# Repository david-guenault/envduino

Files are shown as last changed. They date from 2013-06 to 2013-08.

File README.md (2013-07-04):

# Envduino Project

## Goals

  There was two main goals when i started this project. Having fun with electronics and create a cheap (really) environmental sensor.
  So there it is. Cheap, full featured and usable with either serial or ethernet connection. 
  
  Curently envduino only provide temperature, humidity, pressure and elevation. It should provide in the future light sensing and gaz sensing.

## Included

  envduino is made of a sketch file for arduino (only tested on mega and should not work en leonardo), a shell for getting values and settings preferences (saving not ready at the moment), a nagios/shinken/icinga plugin for checking environmental status and a little webapp for getting metrics and graph them.

## Envduino prototype wiring

### DHT22 

  DHT22 come with 4 pins from left to right when facing the grid
  
  ```

    DHT22                       ARDUINO MEGA 2560

    1 - VCC (3 to 5V)   -->     PIN 3.3V 
    2 - Data Out        -->     PIN 2 (this can be changed in the arduino sketch)
    3 - Not connected
    4 - Ground          -->     GROUND PIN

  ```

  Also connect a 10k resistor between DHT22's VCC AND DATA pins

### BMP085

  There are 7 pins from left to right (1 to 7). This is an i2c module. 

```
    BMP085                      ARDUINO MEGA 2560

    1 - 5V             
    2 - 3.3V            -->     3.3V
    3 - GROUND          -->     Ground
    4 - SDA             -->     PIN 43 SDA
    5 - SCL             -->     PIN 42 SCL
    6 - XCLR
    7 - EOC
```

### Schematic 

#### breadboard



#### logical 



## Envduino Shell

This shell allow to test envduino module and configure envduino module settings

```
------------------------------------------------

Welcome to Envduino Shell

(c) David GUENAULT

david.guenault@gmail.com

Released under GNU Affero General Public License

http://www.gnu.org/licenses

------------------------------------------------

> connect
Using default port and baudrate (/dev/ttyACM1,9600)
Connection to serial port OK

> temperature
temperature:24
> humidity
humidity:55
> 
```

## Envduino serial commands protocol

### Checking envduino is alive

```
   Syntax : ping
   Return : pong
```

### Thresholds

#### Setting 

 Settings thresholds is done through the envduino shell tool or through arduino serial console.

```
    syntax : t;[s];[t];[v]
    t define that the current command is a threshold setting command
    [s] is the sensor :
        h for humidity
        t for temperature
        p for pressure
    [t] is the threshold type. For the thow levels of alert (warning and critical)
        w for warning
        c for critical
    [v] is the threshold value. It's an integer within bounds of your sensor.
````

#### Reading 

```
    syntax : r
    Return : Temperature : w=-9999, c=-9999 | Humidity : w=-9999,c=-9999 | Pressure : w=-9999,c=-9999
```

#### Saving 

```
    Syntax : w (NOT IMPLEMENTED)
    Return : 
```

#### Visual status indicator

 Visual status is a way to define if mesured sensor values are within bounds or not by colored leds. 

 There are 3 leds on the project (red,yellow,gree). Each led is a visual status indicator. 
 * Green: OK
 * Yellow: WARNING
 * Red: CRITICAL

##### Controling leds

```
    Syntax : l;[led];[state]
    Return : 

    led should be one of the following :
    r for red
    y for yellow
    g for green

    state should be one of the following :
    0 for off
    1 for on
```

### geting sensors values

```
    Syntax : m;[sensor]
    Return : temperature:25

    sensor should be one of the following :
    h for humidity
    t for temperature
    p for pressure
```

## Preparing the environment

### DEBIAN/UBUNTU

envduino use the following libraries (allready included in this github space).

 * Adafruit DHT22 library : https://github.com/adafruit/DHT-sensor-library
 * Adafruit BMP085 library : https://github.com/adafruit/Adafruit-BMP085-Library
 
## Parts

### List

 * 1		10k Ω Resistance				
 * 3		330 Ω Resistance	
 * 1		DHT22 Humidity and Temperature Sensor	
 * 1		Arduino Mega	
 * 1		BMP085 Breakout (pressure and elevation)	
 * 1		Yellow LED 
 * 1		Red LED 
 * 1		Green LED 

### Where to buy 

I bought everything on amazon (no pub but it was cheaper). 
  
  * BMP085 pressure, elevation and temperature sensor (http://www.amazon.fr/gp/product/B0090XB5GQ/ref=oh_details_o02_s00_i00?ie=UTF8&psc=1)
  * DHT22 humidity and tempertature sensor (http://www.amazon.fr/gp/product/B005A9KJ4I/ref=oh_details_o04_s00_i00?ie=UTF8&psc=1)
  * Ethernet Shield (http://www.amazon.fr/gp/product/B00D6BGCO8/ref=oh_details_o03_s00_i00?ie=UTF8&psc=1)
  * Arduino mega clone (http://www.amazon.fr/Arduino-MEGA-2560-Board-Conseil/dp/B00C04P9VO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)
  * 10k resistor

You can also find the parts at the following websites
  
  * http://www.adafruit.com (US)
  * http://www.arduino.cc (for arduino mega and ethernet shield) (EU)
  * http://https://www.sparkfun.com (US)

As an alternative you can use the sainsmart bmp085 (cheaper) from : http://www.sainsmart.com/sainsmart-bmp085-digital-pressure-sensor-module-board.html

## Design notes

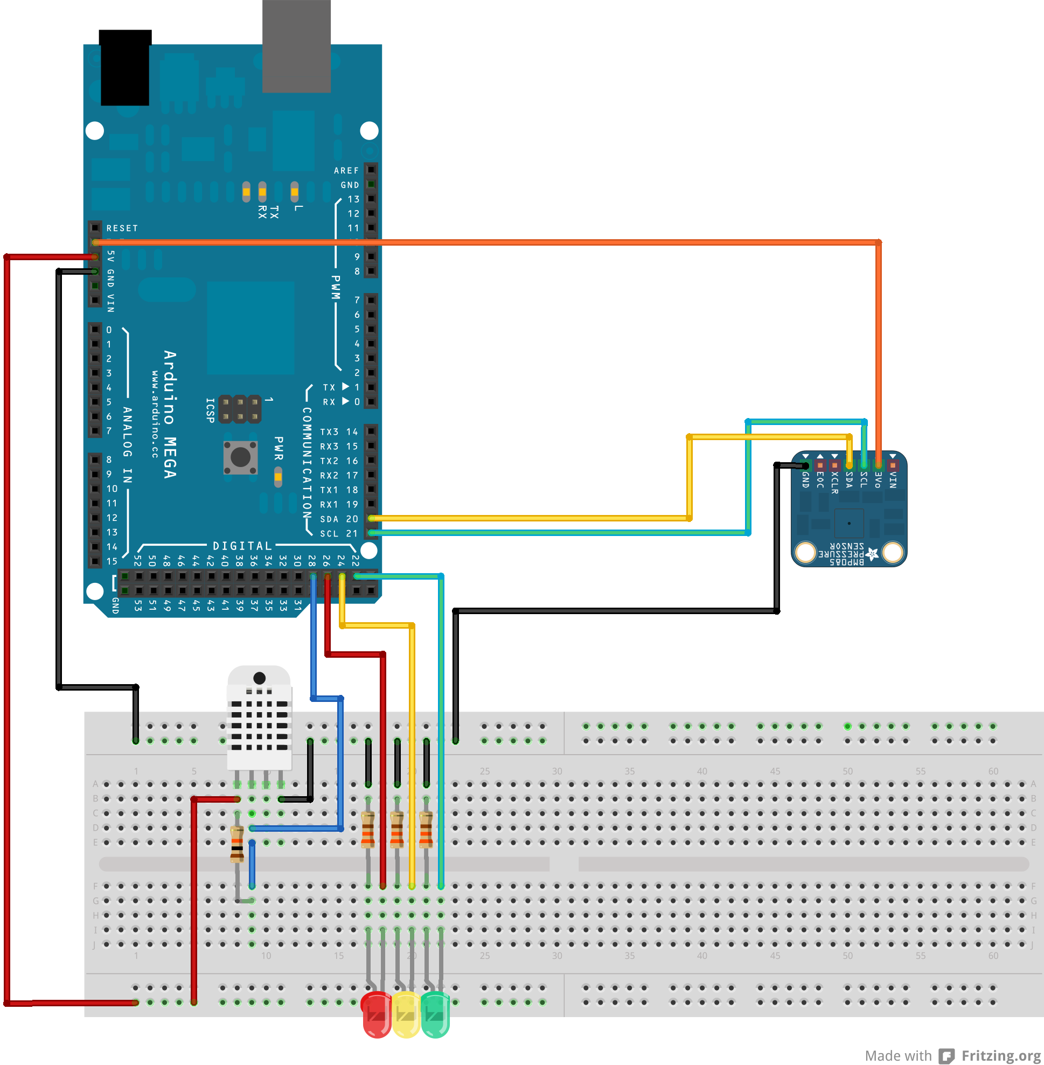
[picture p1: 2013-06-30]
schematic/envduino_bb.png

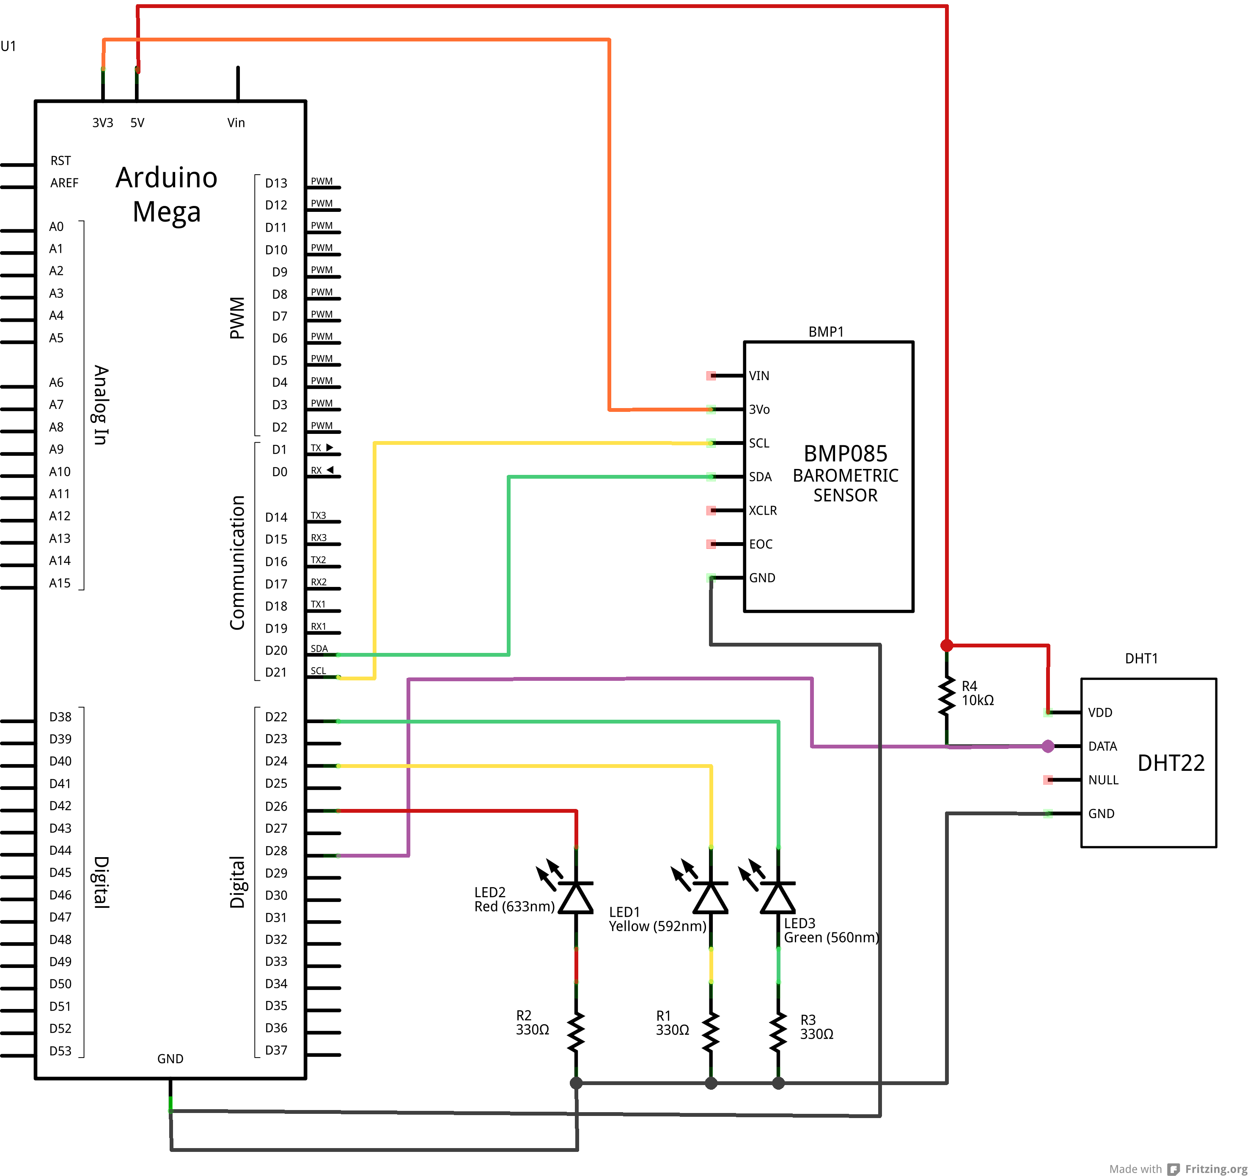
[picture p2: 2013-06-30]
schematic/envduino_schema.png

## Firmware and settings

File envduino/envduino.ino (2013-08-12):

#include <Arduino.h>
#include <EEPROM.h>
#include <Wire.h>
#include <DHT.h>
#include <BMP085.h>
#include <SEMAPHORE.h>
#include <THRESHOLDS.h>
#include <SENSORS.h>

#define DHTPIN 28
#define DHTTYPE DHT22

#define BMP085_ADDRESS 0x77
#define BMP085_OSS 0
#define BMP085_PRESSURE_SEA_LEVEL 102100


// 2 dimensions char array used to store data read from serail
const int MAX_COLS = 5; 
const int MAX_ROWS = 4;
char data[MAX_COLS][MAX_ROWS];

// serial parameters
const int BAUDRATE = 9600;
const int MAX_MESSAGE_SIZE = 20;
char message[MAX_MESSAGE_SIZE];
int index = 0;

// command parameters
const char SEPARATOR = ';';
char EOL[] = "EOL";
char EOC[] = "EOC";
const int BUFSIZE = 255;

// flag for message read completion
boolean messageComplete = false;

// do we need to print debug messages
boolean DEBUG = false;

//PINS FOR LEDS
const int  RED = 22;
const int  YELLOW = 24;
const int  GREEN = 26;
const boolean  USELEDS = true;
SEMAPHORE semaphore(RED,YELLOW,GREEN);

// Thresholds management
THRESHOLDS thresholds;

// Sensors
SENSORS sensors;

void resetBuffer(char* buf){
  int i = 0;
  for (i = 0;i<BUFSIZE+3;i++) buf[i] = '\0';
}

void processCommand(){
  char b[BUFSIZE+3];
  char command[MAX_COLS];
  char arg1[MAX_COLS];
  char arg2[MAX_COLS];  
  char arg3[MAX_COLS];    
  int length=0;
  
  logln("process command");
  
  getField(0,command);
  
  if ( strcmp(command,"t") == 0){
    
    getField(1,arg1);
    getField(2,arg2);
    getField(3,arg3);    
    int ivalue = atoi(arg3);
    thresholds.set(arg1[0],arg2[0],ivalue);
    eoc();
    
  }else if ( strcmp(command,"d") == 0) {
    getField(1,arg1);
    if (strcmp(arg1,"1") == 0){
      setDebug(true);
      Serial.println("Debug is on");
    }else if(strcmp(arg1,"0") == 0){
      setDebug(false);
      Serial.println("Debug is off");
    }
    eoc();
  }else if ( strcmp(command,"w") == 0 ) {
    eoc();
  } else if ( strcmp(command, "p") == 0) {
    Serial.print("pong");
    eoc();
  }else if ( strcmp(command,"r")  == 0) {
    char b[255];
    int temperature[2];
    int pressure[2];
    int humidity[2];
    thresholds.get('t',temperature);
    thresholds.get('h',humidity);
    thresholds.get('p',pressure);
    sprintf(b, "Temperature : w=%d, c=%d | Humidity : w=%d,c=%d | Pressure : w=%d,c=%d",temperature[0],temperature[1],humidity[0],humidity[1],pressure[0],pressure[1]);
    Serial.print(b);
    eoc();
  }else if ( strcmp(command, "l")  == 0 ){
    getField(1,arg1);    
    getField(2,arg2);
    int state = atoi(arg2);
    if ( state == 0 || state == 1 ) {
      if ( strcmp(arg1, "r")  == 0 ){
        semaphore.red(state);
      }else if ( strcmp(arg1, "y")  == 0 ){
        semaphore.yellow(state);
      }else if ( strcmp(arg1, "g")  == 0 ){
        semaphore.green(state);
      }
    }
    eoc();
  }else if( strcmp(command, "m") == 0 ){
    char type[MAX_COLS];
    int mesure;
    mesure = 0;
    getField(1,type);
    sensors.mesure();
    if ( type[0] == 't' ){
      mesure = sensors.temperature();
      sprintf(b,"temperature:%i",mesure);
    }else if (type[0] == 'h'){
      mesure = sensors.humidity();
      sprintf(b,"humidity:%i",mesure);
    }else if (type[0] == 'p'){
      long pressure = (long)(sensors.pressure()*0.01);
      sprintf(b,"pressure:%ld",pressure);
    }else{
      eoc();
      return;
    }
    int state = thresholds.check(*type,mesure);
    semaphore.alarm(state);
    Serial.print(b);
    eoc();
  }
  clearMessageBuffer();
  clearData();
}

int getField(int row, char* field){
  int length=0;
  while (data[row][length] != '\0'){
    field[length] = data[row][length];
    length++;
  }
  field[length] = '\0';
  return length;
}

/*****************************************************************
*
* UTILITY FUNCTIONS
*
*****************************************************************/

// Active / Deactivate debug mode 
boolean setDebug(boolean debug){
  DEBUG = debug;  
  return true;
}

void logln(char* dlog){
  // debug data over serial with end of line
  if(DEBUG){
    log(dlog);
    log(EOL);
  }
}

void log(char* dlog){
  // debug data over serial 
  if (DEBUG) Serial.print(dlog);  
}

void eoc(){
  // send end of communication
  Serial.print(EOC);
}

void eol(){
  // send end of line
  Serial.print(EOL);
}

/*****************************************************************
 * 
 * RELATED TO SERIAL COMMAND READING
 * 
 ******************************************************************/

void clearMessageBuffer(){
  for ( int i = 0; i<MAX_MESSAGE_SIZE; i++) message[i] = '\0' ;
  index = 0;
}

// get number of fields
int getMessageSize(){
  int i = 0;
  while( message[i] != '\0' && message[i] != '\n' && message[i] != '\r' ){
    i++;
  }
  return i;
}

// clean up existing splitted data
void clearData(){
  for ( int r = 0; r < MAX_ROWS; r++ ){
    for ( int c = 0; c < MAX_COLS; c++ ){
      data[r][c] = '\0';
    }
  }  
}

void splitMessage(){
  // ok message is complete split fields and store it 
  int msize = getMessageSize(); 
  int row = 0;
  int col = 0;
  for(int i = 0; i<msize; i++){
    if (message[i] == SEPARATOR){
      // end of field
      data[row][col] = '\0';
      row++;
      col=0;
    }
    else{
      if (message[i] != '\0'){
        data[row][col] = message[i];
        col++;
      }
    }
  }  
}

void serialEvent(){
  clearData();
  while (Serial.available() && index < MAX_MESSAGE_SIZE) {
    message[index] = (char)Serial.read();
    if (message[index] == '\n' || message[index] == '\r') {
      messageComplete = true; 
      logln(message);
      break;
    } 
    index++;
  }    
}

/*****************************************************************
 * 
 * INIT AND MAIN LOOP
 * 
 ******************************************************************/

void setup(){
  logln("Start setup");
  Serial.begin(BAUDRATE);
  sensors.begin();
  pinMode(RED, OUTPUT);  
  pinMode(GREEN, OUTPUT);  
  pinMode(YELLOW, OUTPUT);    
  
  //dht.begin();
 
  
  clearData();
  clearMessageBuffer();
  logln("End setup");
}
  
void loop(){
  if ( messageComplete ){
    logln("Message is complete");
    splitMessage();
    processCommand();
    messageComplete = false; 
  }
}

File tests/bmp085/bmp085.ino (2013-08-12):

#include <Arduino.h>
#include <Wire.h>
#include <DHT.h>
#include <BMP085.h>
#include <SENSORS.h>
// sensor parameters
#define BMP085_OSS 0
#define BMP085_ADDRESS 0x77
#define BMP085_PRESSURE_SEA_LEVEL 102100

long pressure;
SENSORS sensors;

void setup(){
  Serial.begin(9600);  
  sensors.begin();
  pressure = 0;
}

void loop(){
  sensors.mesure();  
  pressure = sensors.pressure();
  Serial.println(pressure);
  delay(2000);
}

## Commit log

2013-06-14 Started to add schematic
    [envduino.fz]
2013-06-16 Updated fritzing project schema
    [envduino.fzz]
2013-06-16 removed old schema
    [envduino.fz]
2013-06-18 Fix some messages output
    [envduino.ino]
2013-06-28 added wiring file with pin connections
2013-06-29 Added schematic section
2013-06-29 Updated fritzing schema
    [envduino.fzz]
2013-06-29 Added a dedicated library to handle leds
2013-06-29 Update breadboard schematic
    [envduino.fzz]
2013-06-29 Updated schematic in readme.md
2013-06-30 Added semaphore library to control leds
2013-06-30 added schematic view
2013-06-30 Updated fritzing schemas
    [envduino.fzz]
2013-07-02 Added a wrapper library for sensors reading
2013-07-02 Modified the Adafruit DHT library so it can initialize type and pin later
2013-07-02 Finally temperature and humidity are ready
2013-07-03 Updated schema
    [envduino.fzz]
2013-07-03 Updated included libraries in sensors.ino test
2013-08-12 Finaly got three sensors working
2013-08-12 Remove unused arduino code
